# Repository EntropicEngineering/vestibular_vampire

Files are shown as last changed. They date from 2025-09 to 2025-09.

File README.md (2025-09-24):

Based on a modified version of the  [Howland VCCS For GVS Experiment from the Digital Nature Group](https://github.com/DigitalNatureGroup/Howland-VCCS-for-GVS-experiment-prototype)

[Link to Digital Nature Group MIT License](https://github.com/DigitalNatureGroup/Howland-VCCS-for-GVS-experiment-prototype/blob/main/MIT%20License)

[Link to Digital Nature Group CERN OHL-W](https://github.com/DigitalNatureGroup/Howland-VCCS-for-GVS-experiment-prototype/blob/main/LICENSE)

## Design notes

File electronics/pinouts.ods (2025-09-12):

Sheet: STUSB4500_USB_PD
Pin Number | Pin Name | Electrical Type | Group | Description
1 | IN+ | Input |  | Positive differential shunt voltage. Connect to positive side of shunt resistor.
2 | IN- | Input |  | Negative differential shunt voltage. Connect to negative side of shunt resistor. Bus voltage is measured from this pin to ground.
3 | GND | Power |  | Ground
4 | Vs | Power |  | Power supply, 3 to 5.5 V
5 | SCL | Input |  | Serial bus clock line
6 | SDA | I/O |  | Serial bus data line
7 | A0 | Input |  | I2C address pin.
8 | A1 | Input |  | I2C address pin.

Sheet: MCP4725 DAC
Pin Number | Pin Name | Electrical Type | Group | Description
1 | VOUT | Output |  | Analog Output Voltage
2 | VSS | Power |  | Ground Reference
3 | VDD | Power |  | Supply Voltage
4 | SDA | I/O |  | I2C Serial Data
5 | SCL | Input |  | I2C Serial Clock Input
6 | A0 | Input |  | I2C Address Bit Selection pin (A0 bit). This pin can be tied to VSS or VDD, or can be actively driven by the digital logic levels.

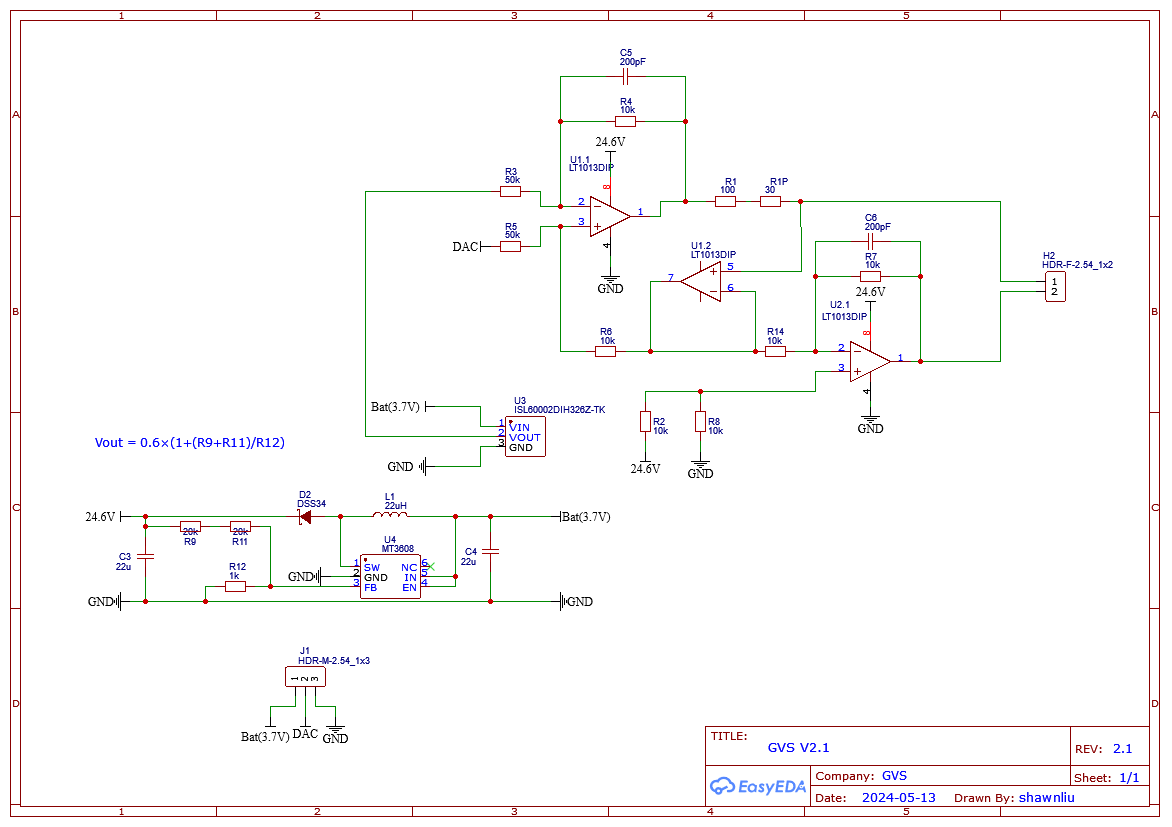
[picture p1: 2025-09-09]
electronics/inspiration_schematic.png

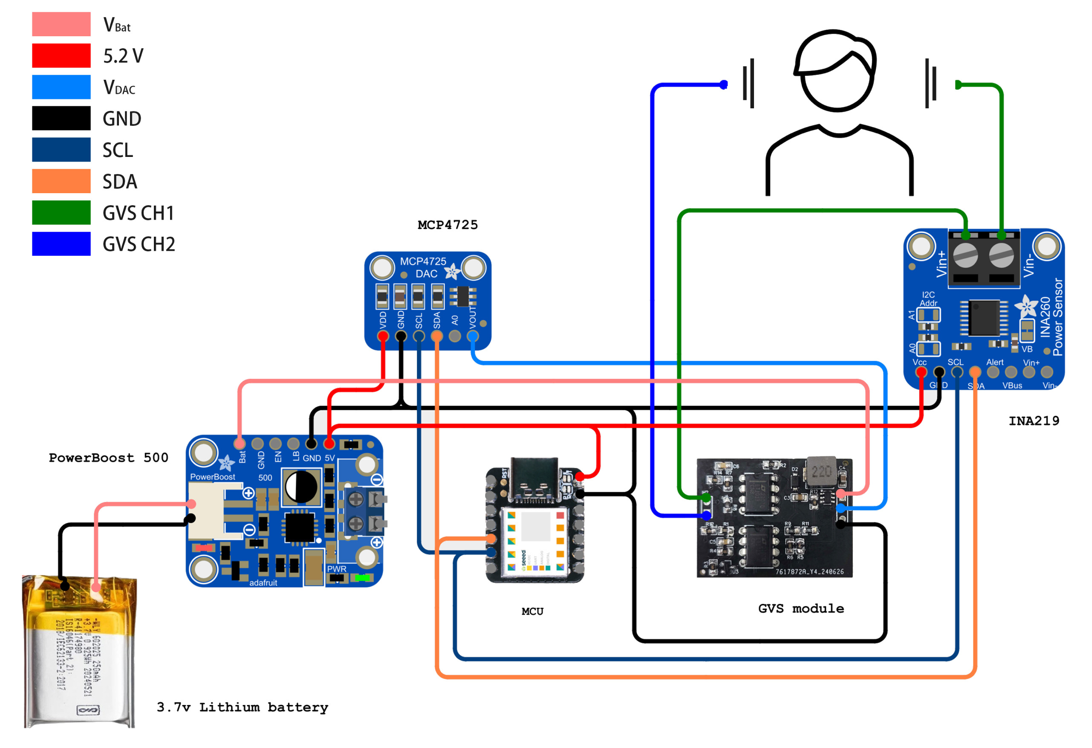
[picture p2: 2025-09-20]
electronics/inspiration_block_diagram.jpg

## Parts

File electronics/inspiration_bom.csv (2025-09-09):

Name | Designator | Footprint | Quantity | Manufacturer Part
22u | C3,C4 | C0805 | 2
200pF | C5,C6 | C0805 | 2 | VJ0805D201KXAAT
DSS34 | D2 | SOD-123_L2.8-W1.8-LS3.7-RD | 1 | DSS34
HDR-F-2.54_1x2 | H2 | HDR-F-2.54_1X2 | 1
HDR-M-2.54_1x3 | J1 | HDR-M-2.54_1X3 | 1
22uH | L1 | IND-SMD_L7.1-W6.6 | 1 | SMMS0650-220M
100 | R1 | R0805 | 1
30 | R1P | R0805 | 1
10k | R2,R4,R6,R7,R8,R14 | R0805 | 6
50k | R3,R5 | R0805 | 2
20k | R9,R11 | R0805 | 2
1k | R12 | R0805 | 1
ISL60002DIH326Z-TK | U3 | SOT-23-3_L2.9-W1.3-P1.90-LS2.4-BR | 1 | ISL60002DIH326Z-TK
MT3608 | U4 | SOT-23-6_L2.9-W1.6-P0.95-LS2.8-BL | 1 | MT3608
LT1013DIP | U1,U2 | PDIP-8_L9.6-W6.4-P2.54-LS7.6-BL | 2 | LT1013DIP

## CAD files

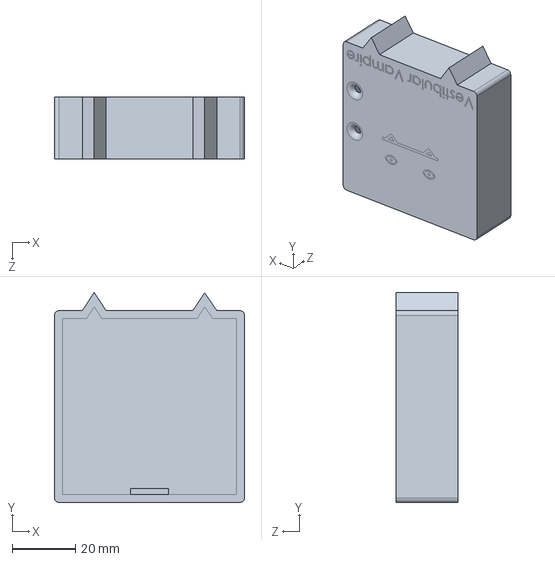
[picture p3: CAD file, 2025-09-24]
housing/housing.sldprt
60.2 x 66.5 x 19.5 mm

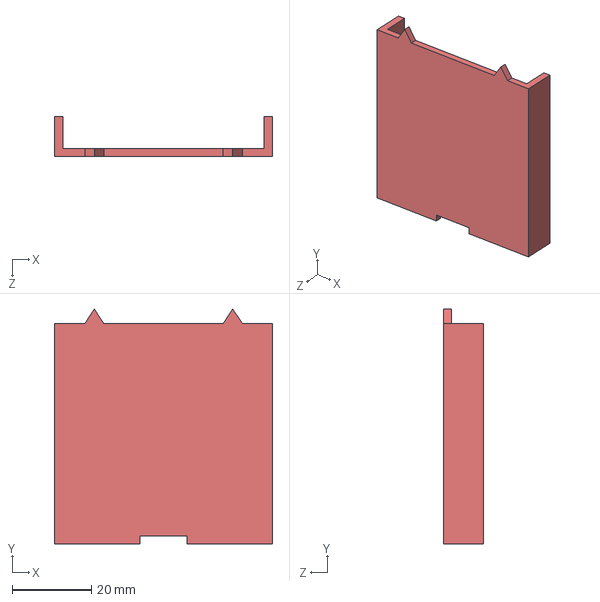
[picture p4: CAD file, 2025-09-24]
housing/housing_bottom.step
55.2 x 59.5 x 10.0 mm

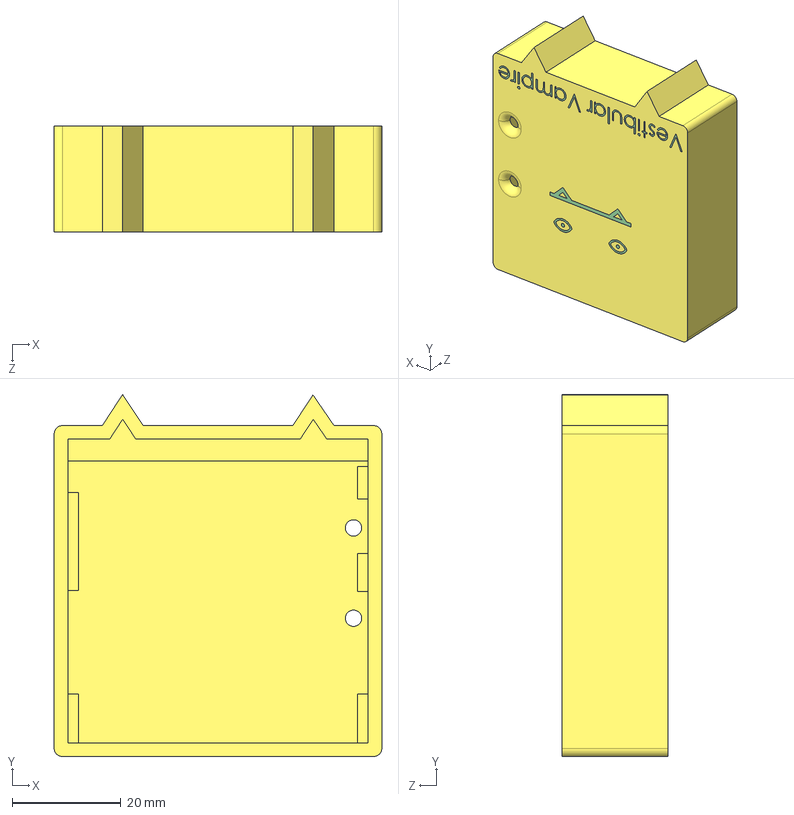
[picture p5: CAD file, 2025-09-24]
housing/housing_top.step
60.2 x 66.5 x 19.5 mm

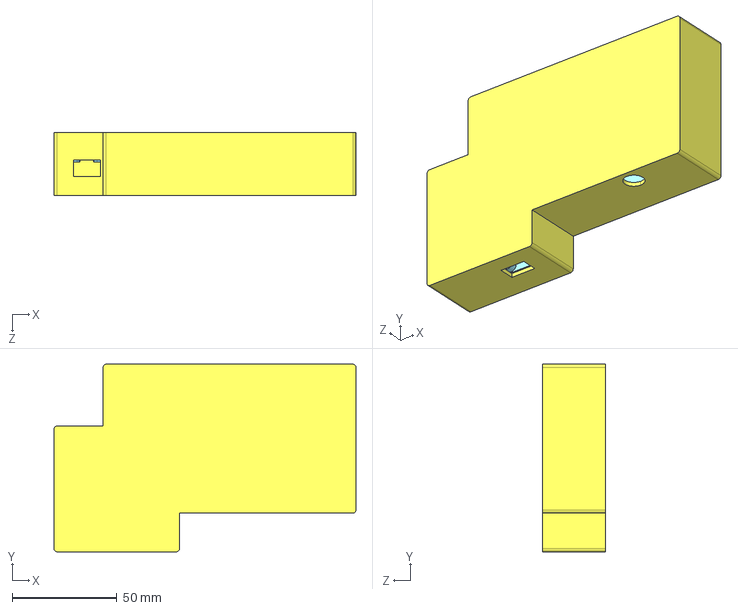
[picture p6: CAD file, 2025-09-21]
housing/dev_kit_mounting_plate.step
143.9 x 89.4 x 30.0 mm

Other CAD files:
housing/dev_kit_mounting_plate.sldprt

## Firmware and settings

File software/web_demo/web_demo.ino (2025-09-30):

#include <WiFi.h>
#include <WebServer.h>
#include <DNSServer.h>
#include <Wire.h>
#include <Adafruit_MCP4725.h>
#include <Adafruit_INA219.h>
#include <Adafruit_NeoPixel.h>
#include <math.h>
#include <Arduino.h>

#define SDA_PIN 14
#define SCL_PIN 15
#define V5V_EN_PIN 13
#define V24V_EN_PIN 22
#define VREF_EN_PIN 20
#define ASENSE_EN_PIN 3
#define RGB_LED_PIN 16
#define BUTTON1_PIN 21  //Active low.
#define BUTTON2_PIN 26  //Active low.
#define BATT_CHARGING_PIN 27  //Active low.
#define BATT_FULL_PIN 28  //Active low.

#define DAC_ADDRESS 0x60
//#define DAC_ADDRESS 0x62  //Dev kit only.
#define ASENSE_ADDRESS 0x40
#define IMU_ADDRESS 0x19

#define RGB_LED_COUNT 7 //The "teeth" are #1 and #5.  Center is #3.

#define BAUD_RATE 115200
#define STARTUP_DELAY 0
#define SLEEP_TIMEOUT_SECONDS 600 //Seconds of inactivity before activating sleep mode.

#define SSID "Vestibular Vampire"
#define PASSWORD "12345678"

#define BUTTON1_CURRENT 3.0
#define BUTTON1_SLOPE 200
#define BUTTON1_DURATION  1000

#define BUTTON2_CURRENT -3.0
#define BUTTON2_SLOPE 200
#define BUTTON2_DURATION  1000

//Sleep timer.
unsigned long last_activity = 0;
bool interrupt = 0;

// Slider values
float current_slider = 0.0; //Range: -3.5 to 3.5 mA
int slope_slider = 50;     //Range: 0 to 2000 ms
int duration_slider = 50;  //Range: 0 to 5000 ms

//Instantiate current sensor.
Adafruit_INA219 asense(ASENSE_ADDRESS);
//Instantiate DAC.
Adafruit_MCP4725 dac;
//Instantiate RGB LEDs.
Adafruit_NeoPixel rgb_leds = Adafruit_NeoPixel(RGB_LED_COUNT, RGB_LED_PIN, NEO_GRB + NEO_KHZ800);

float currentValue = 0.0;
int slopeValue = 0;
int durationValue = 0;
float offset = 0.085;   //Offset current (mA).
float current_mA = 0;

unsigned long lastPrintTime = 0;
const unsigned long printInterval = 50;

unsigned long sineWaveStartTime = 0;
int sineWaveStep = 0;
bool sineWaveRunning = false;
int sineWaveSteps = 0;
int sineWaveDelayTime = 0;
int sineWaveAmplitude = 0;
int sineWaveOffsetValue = 0;
int sineWaveFinalDuration = 0;
unsigned long sineWaveFinalStartTime = 0;
bool sineWaveHoldFinalVoltage = false;
bool sineWaveReturnToMidpoint = false;


/////////////////////////////////////////////////
//Web page.


// Captive portal DNS settings
const byte DNS_PORT = 53;
DNSServer dnsServer;

// Web server on port 80
WebServer server(80);

// Web UI HTML
const char* htmlPage = R"rawliteral(
<!DOCTYPE html>
<html>
<head>
  <meta charset="UTF-8">
  <title>Vestibular Vampire</title>
  <style>
    body
    {
      font-family: 'Segoe UI', Tahoma, Geneva, Verdana, sans-serif;
      background-color: #f0f0f0;
      text-align: center;
    }

    h1
    {
      color: black;
      margin-top: 0.1em;
      margin-bottom: 0.5em;
      font-size: 5.5em;
    }

    h2
    {
      color: black;
      font-size: 2em;
    }

    .slider-container {
      background: #fff;
      box-shadow: 0 0.5em 1em rgba(0,0,0,0.1);
      padding: 1em 1em;
      margin: 2.5rem 1rem 0 1rem;
    }

    label {
      font-size: 4em;
      display: block;
    }

    .lr {
      font-size: 4em;
      display: block;
      margin: 0;
    }

    input[type=range] {
      -webkit-appearance: none;
      width: 100%;
      height: 2em;
      background: #ddd;
      border-radius: 1em;
      outline: none;
      transition: background 0.3s;
      margin: 3rem 0;
    }

    input[type=range]::-webkit-slider-thumb {
      -webkit-appearance: none;
      appearance: none;
      width: 7rem;
      height: 7rem;
      border-radius: 50%;
      background: #b81d1d;
      cursor: pointer;
      box-shadow: 0 0.5em 1em rgba(0,0,0,0.1);
    }

    input[type=range]::-moz-range-thumb {
      width: 7rem;
      height: 7rem;
      border-radius: 50%;
      background: #b81d1d;
      cursor: pointer;
    }

    .value-display {
      font-weight: bold;
      color: #b81d1d;
    }

    #sendButton {
      width: calc(100% - 40px);
      padding: 0.5em 0 0.5em 0;
      margin: 8rem 1rem 0 1rem;
      font-size: 3em;
      font-weight: bold;
      border: none;
      background-color: #b81d1d;
      color: white;
      cursor: pointer;
      box-shadow: 0 0.5em 1em rgba(0,0,0,0.1);
      transition: background-color 0.3s;
    }

  </style>
</head>
<body>
  <h1>Vestibular Vampire</h1>

  <div class="slider-container">
    <label>Current (mA): <span id="val1" class="value-display">0</span></label>
    <p class="lr" style="text-align:left; color: #0000b8;">Left<span style="float:right; color: #b81d1d;">Right</span>
    <input type="range" id="slider1" min="-3.5" max="3.5" step="0.1" value="0">
  </div>

  <div class="slider-container">
    <label>Slope (ms): <span id="val2" class="value-display">200</span></label>
    <input type="range" id="slider2" min="0" max="2000" step="10" value="200">
  </div>

  <div class="slider-container">
    <label>Duration (ms): <span id="val3" class="value-display">500</span></label>
    <input type="range" id="slider3" min="0" max="5000" step="10" value="500">
  </div>

  <h2>Made by Rachel at Entropic Engineering</h2>

  <button id="sendButton">Send</button>

  <p>This device is based on the research of Zhi Liu, Shieru Suzuki, Tatsuki Fushimi, and Yoichi Ochiai.</p>

  <script>
    const sliders = ['slider1', 'slider2', 'slider3'];

    sliders.forEach(id => {
      const slider = document.getElementById(id);
      const valSpan = document.getElementById("val" + id.slice(-1));
      slider.addEventListener("input", () => {
        valSpan.textContent = slider.value;
      });
    });

    document.getElementById("sendButton").addEventListener("click", () => {
      const s1 = document.getElementById("slider1").value;
      const s2 = document.getElementById("slider2").value;
      const s3 = document.getElementById("slider3").value;

      fetch(`/set?slider1=${s1}&slider2=${s2}&slider3=${s3}`)
        .then(response => {
          if (!response.ok) {
            alert("Failed to send values");
          }
        });
    });
  </script>
</body>
</html>
)rawliteral";



//End web page.
////////////////////////////////////////////////////////////////////


// Serve root HTML page
void handleRoot() {
  server.send(200, "text/html", htmlPage);
}

// Handle slider updates
void handleSet() {
  if (server.hasArg("slider1")) {
    current_slider = server.arg("slider1").toFloat();
  }
  if (server.hasArg("slider2")) {
    slope_slider = server.arg("slider2").toInt();
  }
  if (server.hasArg("slider3")) {
    duration_slider = server.arg("slider3").toInt();
  }

  server.send(200, "text/plain", "OK");

  Serial.print("Current slider: ");
  Serial.println(current_slider);
  Serial.print("Slope slider: ");
  Serial.println(slope_slider);
  Serial.print("Duration slider: ");
  Serial.println(duration_slider);

  apply();
}

// Redirect unknown URLs to captive portal
void handleNotFound() {
  server.sendHeader("Location", "/", true);
  server.send(302, "text/plain", "");
}

void apply()
{
  currentValue = current_slider;
  slopeValue = slope_slider;
  durationValue = duration_slider;

  if (currentValue >= -4 && currentValue <= 4 && slopeValue > 0 && durationValue > 0) {
    int inputValue = mapFloat(currentValue, -4.0, 4.0, 0, 4095);
    sineWaveOffsetValue = mapFloat(offset, -4.0, 4.0, 0, 4095) - 2048;
    sineWaveAmplitude = inputValue - 2048;
    sineWaveSteps = slopeValue;
    sineWaveDelayTime = slopeValue / sineWaveSteps; 
    sineWaveFinalDuration = durationValue;
    sineWaveStep = 0;
    sineWaveRunning = true;
    sineWaveHoldFinalVoltage = false;
    sineWaveReturnToMidpoint = false;
    sineWaveStartTime = millis(); 
  } else {
    //Serial.println("Invalid parameters");
  }

  //Reset sleep timeout.
  last_activity = millis();
}

void handleSineWave()
{
  if (sineWaveRunning)
  {
    if (sineWaveStep < sineWaveSteps) {
      // Ascending
      if (millis() - sineWaveStartTime >= sineWaveDelayTime) {
        float angle = (PI / 2.0) * (float)sineWaveStep / (float)sineWaveSteps;
        int voltage = 2048 + sineWaveAmplitude * sin(angle) + sineWaveOffsetValue;
        dac.setVoltage(voltage, false);
        sineWaveStep++;
        sineWaveStartTime = millis();
      }
    } else if (!sineWaveHoldFinalVoltage) {
      // Holding
      int finalVoltage = 2048 + sineWaveAmplitude * sin(PI / 2.0) + sineWaveOffsetValue;
      dac.setVoltage(finalVoltage, false);
      sineWaveFinalStartTime = millis();
      sineWaveHoldFinalVoltage = true;
    } else if (sineWaveHoldFinalVoltage && (millis() - sineWaveFinalStartTime >= sineWaveFinalDuration)) {
      // Descending 
      if (sineWaveStep < 2 * sineWaveSteps) {
        if (millis() - sineWaveStartTime >= sineWaveDelayTime) {
          float angle = (PI / 2.0) * (float)(sineWaveStep - sineWaveSteps) / (float)sineWaveSteps;
          int voltage = 2048 + sineWaveAmplitude * sin(PI / 2.0 - angle) + sineWaveOffsetValue;
          dac.setVoltage(voltage, false);
          sineWaveStep++;
          sineWaveStartTime = millis();
        }
      } else if (sineWaveStep >= 2 * sineWaveSteps) {
        // Reset to midpoint
        dac.setVoltage(2048 + sineWaveOffsetValue, false);
        sineWaveRunning = false;
      }
    }

    //Reset sleep timeout.
    last_activity = millis();
  }
}

void printCurrentValues()
{
  if (millis() - lastPrintTime >= printInterval)
  {
    lastPrintTime = millis();
    current_mA = asense.getCurrent_mA();
    //Serial.print("\rCurrent: ");
    //Serial.print(current_mA);
    //Serial.print(" mA");
  }
}

int mapFloat(float x, float in_min, float in_max, int out_min, int out_max) {
  return (x - in_min) * (out_max - out_min) / (in_max - in_min) + out_min;
}

//Short startup animation of the RGB LEDs.  Blocking.
void rgb_startup()
{
  //Turn on one additional LED at a time in sequence.
  for (int i=0; i<RGB_LED_COUNT; i++)
  {
    //Set the LED red.
    rgb_leds.setPixelColor(i, rgb_leds.Color(255, 0, 0));
    //Display this change.
    rgb_leds.show();

    //Small delay before switching to the next LED.
    delay(100);
  }

  //Turn everything off again.
  rgb_leds.clear();
  rgb_leds.show();
}

//Set the RGB lights.
void set_rgb_leds()
{
  //If the unit is outputting a pulse, display light in the corresponding direction.
  if (sineWaveRunning)
  {
    //Turn off any other status indicators.
    rgb_leds.clear();

    //If it's a positive (right) pulse, light LEDs on one side.
    if (currentValue > 0)
    {
      rgb_leds.setPixelColor(0, rgb_leds.Color(200, 0, 0));
      rgb_leds.setPixelColor(1, rgb_leds.Color(200, 0, 0));
    }
    //If it's a negative (left) pulse, light LEDs on the other side.
    else if (currentValue < 0)
    {
      rgb_leds.setPixelColor(6, rgb_leds.Color(200, 0, 0));
      rgb_leds.setPixelColor(5, rgb_leds.Color(200, 0, 0));
    }
  }
  //Otherwise display battery status.
  else
  {
    //Turn off LEDs when done with a pulse.
    rgb_leds.clear();

    //Read the battery status pins, and display light accordingly.
    //If the battery is full, display green.  If charging, display yellow.  Otherwise off.
    if (!digitalRead(BATT_FULL_PIN))
    {
      rgb_leds.setPixelColor(3, rgb_leds.Color(0, 200, 20));

      //Reset sleep timeout.
      last_activity = millis();
    }
    else if (!digitalRead(BATT_CHARGING_PIN))
    {
      rgb_leds.setPixelColor(3, rgb_leds.Color(200, 20, 0));

      //Reset sleep timeout.
      last_activity = millis();
    }
    else
    {
      rgb_leds.setPixelColor(3, rgb_leds.Color(0, 0, 0));
    }
  }
  
  rgb_leds.show();
}

//Read the physical buttons.
void read_buttons()
{
  //Only proceed if the unit is idle.
  if (!sineWaveRunning)
  {
    //If button 1 is pressed, create a pulse.
    if (!digitalRead(BUTTON1_PIN))
    {
      //Create a pulse.
      current_slider  = BUTTON1_CURRENT;
      slope_slider    = BUTTON1_SLOPE;
      duration_slider = BUTTON1_DURATION;

      //Send the pulse.
      apply();
    }
    //If button 2 is pressed, create a pulse.
    else if (!digitalRead(BUTTON2_PIN))
    {
      //Create a pulse.
      current_slider  = BUTTON2_CURRENT;
      slope_slider    = BUTTON2_SLOPE;
      duration_slider = BUTTON2_DURATION;

      //Send the pulse.
      apply();
    }
  }
}

//Enter power-saving sleep mode.
void powerdown()
{
  Serial.println("Going to sleep...");

  //Turn off LEDs.
  rgb_leds.clear();
  rgb_leds.show();

  //Turn off the main output.
  digitalWrite(V24V_EN_PIN, LOW);
  //Turn off current sensor.
  digitalWrite(ASENSE_EN_PIN, LOW);
  //Turn off reference voltage.
//  digitalWrite(VREF_EN_PIN, LOW);
  //Turn of 5V rail (DAC).
//  digitalWrite(V5V_EN_PIN, LOW);

  //Turn off the radio.
  WiFi.disconnect();
  WiFi.mode(WIFI_OFF);
  delay(100);

  //Wake on either button press.
  attachInterrupt(digitalPinToInterrupt(BUTTON1_PIN), powerup, FALLING);
  attachInterrupt(digitalPinToInterrupt(BUTTON2_PIN), powerup, FALLING);

  //Go to sleep, and wait for interrupt.
  while ((millis() - last_activity) > (SLEEP_TIMEOUT_SECONDS * 1000))
  {
    delay(50);
  }
}

void powerup()
{
  //Turn off interrupts.
  detachInterrupt(digitalPinToInterrupt(BUTTON1_PIN));
  detachInterrupt(digitalPinToInterrupt(BUTTON2_PIN));

  //Reset sleep timeout.
  last_activity = millis();

  Serial.println("Powering up!");

  //Bring up current sensor first.
  digitalWrite(ASENSE_EN_PIN, HIGH);
  delay(50);
  //Turn on the reference voltage.
  digitalWrite(VREF_EN_PIN, HIGH);
  delay(50);
  //Turn on the 5V rail (DAC).
  digitalWrite(V5V_EN_PIN, HIGH);
  //Keep the 24V rail off for now (no output to the subject).
  digitalWrite(V24V_EN_PIN, LOW);

  //Set the I2C pins.
  Wire1.setSDA(SDA_PIN);
  Wire1.setSCL(SCL_PIN);
  Wire1.begin();

  //Start DAC.
  dac.begin(DAC_ADDRESS, &Wire1);
  sineWaveOffsetValue = mapFloat(offset, -4.0, 4.0, 0, 4095) - 2048;
  // Reset to midpoint
  dac.setVoltage(2048 + sineWaveOffsetValue, false);

  //Start current sensor.
  asense.begin(&Wire1);
  asense.setCalibration_16V_400mA();

  //Start RGB LEDs.
  rgb_leds.begin();
  //Initialize to off.
  rgb_leds.show();

  // Start WiFi in AP mode
  WiFi.softAP(SSID, PASSWORD);
  IPAddress myIP = WiFi.softAPIP();
  Serial.print("AP IP address: ");
  Serial.println(myIP);

  // Start DNS server wiht captive portal.
  dnsServer.start(DNS_PORT, "*", myIP);

  // Start web server
  server.on("/", handleRoot);
  server.on("/set", handleSet);
  server.onNotFound(handleNotFound);
  server.begin();
  Serial.println("Web server started");

  delay(STARTUP_DELAY);

  //Turn on the main output.
  digitalWrite(V24V_EN_PIN, HIGH);

  //Flash the LEDs to indicate startup is complete.
  rgb_startup();
}

void check_sleep()
{
  if ((millis() - last_activity) > (SLEEP_TIMEOUT_SECONDS * 1000))
  {
    powerdown();
  }
}

void setup()
{
  Serial.begin(BAUD_RATE);

  //Configure IO pins.
  pinMode(V5V_EN_PIN, OUTPUT);
  pinMode(V24V_EN_PIN, OUTPUT);
  pinMode(VREF_EN_PIN, OUTPUT);
  pinMode(ASENSE_EN_PIN, OUTPUT);
  pinMode(RGB_LED_PIN, OUTPUT);

  //Inputs need internal pullups.
  pinMode(BUTTON1_PIN, INPUT_PULLUP);
  pinMode(BUTTON2_PIN, INPUT_PULLUP);
  pinMode(BATT_CHARGING_PIN, INPUT_PULLUP);
  pinMode(BATT_FULL_PIN, INPUT_PULLUP);

  powerup();
}

void loop()
{
  dnsServer.processNextRequest();
  server.handleClient();
  printCurrentValues();
  handleSineWave();
  set_rgb_leds();
  read_buttons();
  check_sleep();
}

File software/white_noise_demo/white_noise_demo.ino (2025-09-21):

#include <Wire.h>
#include <Adafruit_MCP4725.h>
#include <math.h>

#define SDA_PIN 14
#define SCL_PIN 15
#define V5V_EN_PIN 13
#define V24V_EN_PIN 22
#define VREF_EN_PIN 20
#define ASENSE_EN_PIN 3
#define RGB_PIN 16
#define BUTTON1_PIN 21
#define BUTTON2_PIN 26
#define BATT_CHARGING_PIN 27
#define BATT_FULL_PIN 28

#define DAC_ADDRESS 0x62
#define ASENSE_ADDRESS 0x40

#define BAUD_RATE 115200

//Startup delay, (ms).
#define STARTUP_DELAY 3000

Adafruit_MCP4725 dac;

float mapFloat(float x, float in_min, float in_max, float out_min, float out_max)
{
  return (x - in_min) * (out_max - out_min) / (in_max - in_min) + out_min;
}

const int maxAmplitude = 2048;    
const int baseOffset = 2048;      
float offsetD = 0.04;             
float limitedArea = 3.6;          
const int numSteps = 100;          

int noiseTable[numSteps];         

void setup(void)
{
  Serial.begin(BAUD_RATE);

  //Configure IO pins.
  pinMode(V5V_EN_PIN, OUTPUT);
  pinMode(V24V_EN_PIN, OUTPUT);
  pinMode(VREF_EN_PIN, OUTPUT);
  pinMode(ASENSE_EN_PIN, OUTPUT);
  pinMode(RGB_PIN, OUTPUT);

  //Inputs need internal pullups.
  pinMode(BUTTON1_PIN, INPUT_PULLUP);
  pinMode(BUTTON2_PIN, INPUT_PULLUP);
  pinMode(BATT_CHARGING_PIN, INPUT_PULLUP);
  pinMode(BATT_FULL_PIN, INPUT_PULLUP);

  //Set IO pin defaults.
  //Bring up current sensor first.
  digitalWrite(ASENSE_EN_PIN, HIGH);
  delay(50);
  //Turn on the reference voltage.
  digitalWrite(VREF_EN_PIN, HIGH);
  delay(50);
  //Turn on the 5V rail (DAC).
  digitalWrite(V5V_EN_PIN, HIGH);
  //Keep the 24V rail off for now (no output to the user).
  digitalWrite(V24V_EN_PIN, LOW);
  
  //Set the I2C pins.
  Wire1.setSDA(SDA_PIN);
  Wire1.setSCL(SCL_PIN);
  Wire1.begin();

  //Initialize DAC communication, using the proper Wire1 device.
  dac.begin(DAC_ADDRESS, &Wire1);  

  float mappedOffsetD = mapFloat(offsetD, 0, 8.0, 0, 4095);
  float mappedLimitedArea = mapFloat(limitedArea, 0, 8.0, 0, 4095);
  float actualAmplitude = mappedLimitedArea / 2.0;  
  float actualOffset = baseOffset + mappedOffsetD;
  dac.setVoltage((int)actualOffset, false); 
  delay(STARTUP_DELAY);  
  
  //Generate an array of random values, witin constraints.
  for (int i = 0; i < numSteps; i++)
  {
    noiseTable[i] = (int)(random(-maxAmplitude, maxAmplitude) + actualOffset);
    //Original line:
    //noiseTable[i] = (int)(random(-actualAmplitude, actualAmplitude) + actualOffset);

  }

  //Turn on the main output.
  digitalWrite(V24V_EN_PIN, HIGH);
}

void loop()
{
  int delayTime = 100000 / numSteps; 

  //Step through the array of random values.
  for (int i = 0; i < numSteps; i++)
  {
    //Set the output voltage based on the current random value.
    dac.setVoltage(noiseTable[i], false);
    delayMicroseconds(delayTime);  

    //Generate a new random value for this array index.
    noiseTable[i] = (int)(random(-maxAmplitude, maxAmplitude) + baseOffset);
    //Original line:
    //noiseTable[i] = (int)(random(-actualAmplitude, actualAmplitude) + baseOffset);
  }
}

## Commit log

2025-09-09 Starting schematic.
    [inspiration_bom.csv, vestibular_vampire.PrjPcb, vestibular_vampire.SchDoc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]
2025-09-10 Schematic is nearly done.
    [pinouts.ods, vestibular_vampire.PrjPcb, vestibular_vampire.SchDoc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]
2025-09-11 Routing PCB.
    [vestibular_vampire.PrjPcb, vestibular_vampire.SchDoc]
2025-09-12 Finished routing.
    [pinouts.ods, vestibular_vampire.SchDoc, vestibular_vampire.SchLib]
2025-09-13 Added 5V boost and buttons.
    [vestibular_vampire.SchDoc]
2025-09-15 Added antenna cutout. Boards ordered.
2025-09-20 Starting software.
    [Drill_PTH_Through.DRL, Drill_PTH_Through_Via.DRL, Gerber_BoardOutlineLayer.GKO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]
2025-09-21 DAC works. Writing web UI.
    [dev_kit_mounting_plate.sldprt, dev_kit_mounting_plate.step]
2025-09-24 Fixed DAC I2C address, and made housing.
    [housing.sldprt, housing_bottom.step, housing_top.step]
2025-09-25 Added battery charging indicator.
2025-09-27 Added button functions, and LED feedback.
2025-09-30 Added sleep mode, and fixed up GUI.
    [web_demo.ino]
